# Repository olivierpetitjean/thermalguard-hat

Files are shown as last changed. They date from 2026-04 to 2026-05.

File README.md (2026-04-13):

# ThermalGuard HAT

ThermalGuard HAT is a Raspberry Pi HAT for monitoring and controlling airflow in a server rack or enclosed equipment bay.

This repository contains both the hardware design and the software stack:

- a custom KiCad HAT
- a Python hardware service running on the Raspberry Pi
- a .NET 8 API
- an Angular web dashboard

## Demo

https://github.com/user-attachments/assets/547ba5f1-9dda-4290-b39c-db074ba426f6

## Board Renders And Wiring

### KiCad 3D render - front

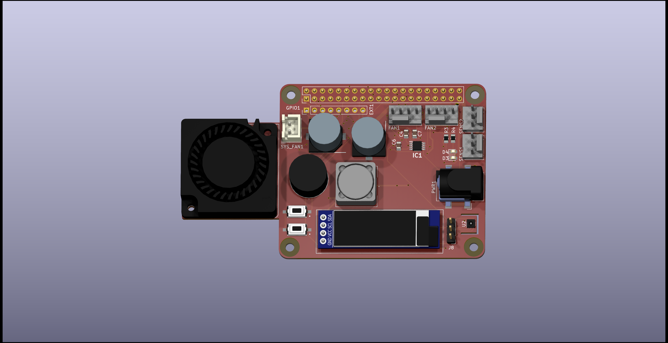
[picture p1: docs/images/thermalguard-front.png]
ThermalGuard HAT front render


### KiCad 3D render - back

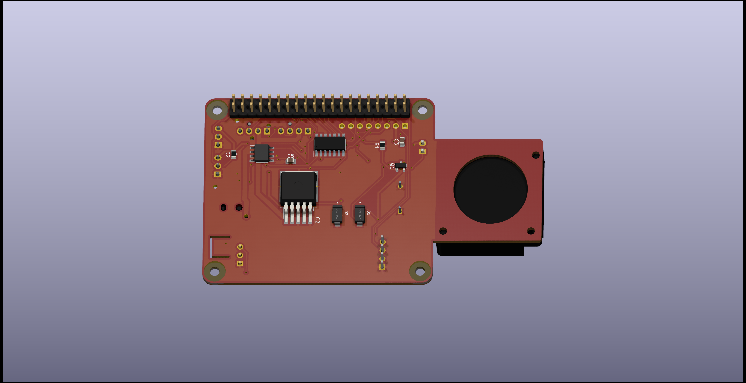
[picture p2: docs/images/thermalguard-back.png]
ThermalGuard HAT back render


### Wiring overview

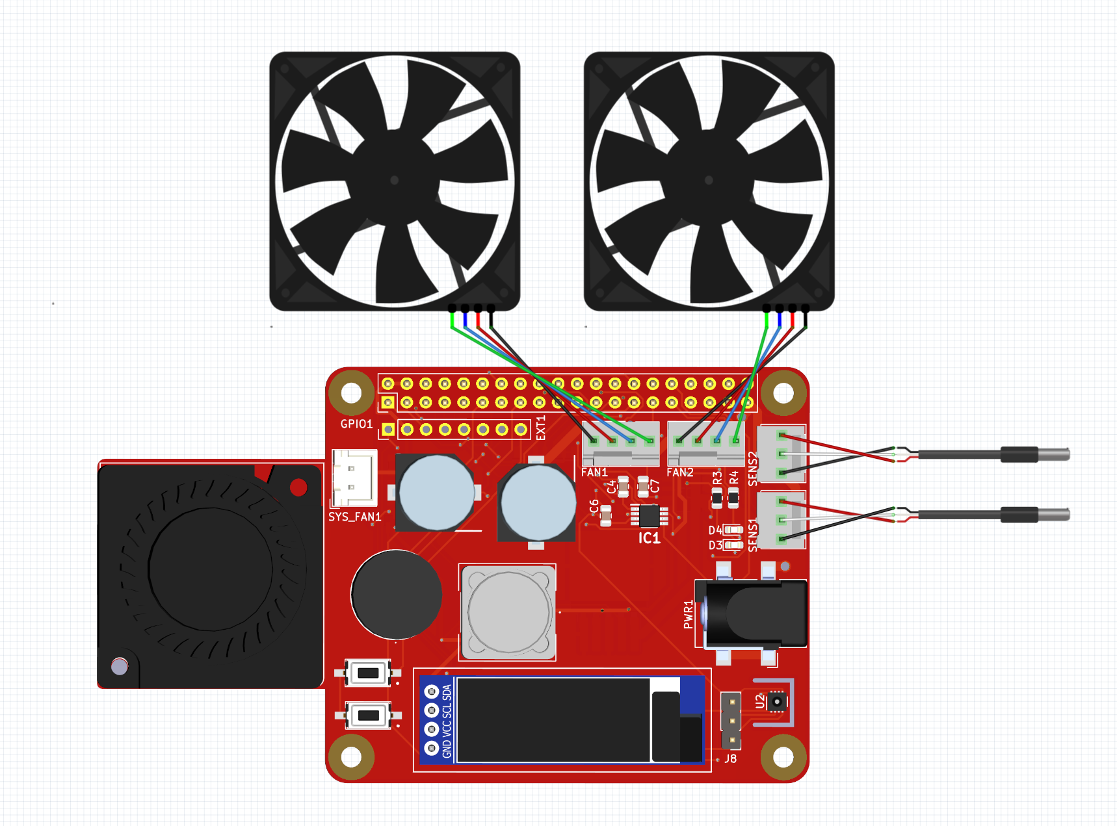
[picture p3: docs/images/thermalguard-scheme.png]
ThermalGuard HAT wiring schematic


## Features

- System monitoring for onboard temperature, power consumption and relative humidity
- Two configurable temperature probes for rack, ambient or custom placement
- Dual fan control with RPM tracking and airflow estimation
- Onboard display showing temperatures, fan RPM, IP address and MAC address
- Automatic fan curves with linked or independent behavior
- Temporary boost mode to force maximum cooling for a defined duration
- Audible alert when a fan or temperature probe is disconnected
- Onboard button control to mute or disable the audible alert
- Web dashboard with live status cards and historical charts
- History browsing by custom period, day or hour
- Local or remote access with authentication
- Kiosk mode for dedicated wall display or rack display usage
- End-to-end installation assistant, including kiosk setup
- Configurable SQLite storage location, including external USB or disk-based storage

The reference platform for this project is a Raspberry Pi 2B. The goal is also to make practical use of older Raspberry Pi hardware for a dedicated monitoring appliance, rather than requiring a newer and more expensive board.

## Repository Structure

```text
thermalguard-hat/
|-- backend/
|   |-- src/      .NET 8 API, persistence, workers, static frontend hosting
|   `-- tests/    .NET test project
|-- frontend/     Angular frontend
|-- services/     Raspberry Pi hardware service and Python tests
|-- kicad/        KiCad project for the HAT PCB
|-- config/       Shared example configuration
|-- docs/         README media assets
`-- install.sh    Raspberry Pi installation script
```

## Hardware

Main hardware blocks currently present in the project:

- Raspberry Pi 2B host
- custom HAT PCB designed in KiCad
- 2 x DS18B20 probes
- 1 x SHT31D temperature and humidity sensor
- 2 x PWM-controlled fans
- fan tachometer and current measurement circuitry
- OLED display and onboard controls

The repository is not only a software project. It also includes the PCB design files required to fabricate the HAT.

## Software Architecture

```mermaid
flowchart TB
    browser([Browser])
    kiosk([Kiosk Display])
    front["Angular Dashboard"]
    api[".NET 8 API"]
    proxy["MQTT Proxy (/mqtt)"]
    mqtt[("Mosquitto Broker")]
    py["Python Hardware Service"]
    db[("SQLite Database")]
    hw["Sensors / Fans / GPIO"]
    svc["systemd"]

    browser -->|"UI"| front
    kiosk -->|"Kiosk UI"| front
    front -->|"REST"| api
    front -->|"WebSocket MQTT"| proxy
    proxy -->|"MQTT"| mqtt
    mqtt -->|"Live telemetry"| proxy
    py -->|"Publish"| mqtt
    py -->|"Store samples"| db
    api -->|"Read / write"| db
    api -->|"Control service"| svc
    svc -->|"Manage"| py
    py -->|"Read / drive"| hw

    classDef client fill:#202534,stroke:#90a4ff,color:#ffffff,stroke-width:1.5px;
    classDef ui fill:#2f3d56,stroke:#6ea8fe,color:#ffffff,stroke-width:1.5px;
    classDef backend fill:#304b46,stroke:#58c4a3,color:#ffffff,stroke-width:1.5px;
    classDef msg fill:#4b3561,stroke:#d08bff,color:#ffffff,stroke-width:1.5px;
    classDef data fill:#5a4330,stroke:#f2a65a,color:#ffffff,stroke-width:1.5px;
    classDef device fill:#4a3f46,stroke:#ff7b7b,color:#ffffff,stroke-width:1.5px;

    class browser,kiosk client;
    class front ui;
    class api,proxy,svc backend;
    class mqtt msg;
    class db data;
    class py,hw device;
```

### Python service

The Python service is the hardware-facing part of the system. It:

- initializes GPIO and sensors
- controls the fans
- reads live measurements
- publishes telemetry on MQTT
- persists data into SQLite

Main entry points:

- [services/main.py](services/main.py)
- [services/service.py](services/service.py)

### Backend API

The backend is a .NET 8 application that:

- serves the web application
- exposes authenticated API endpoints
- stores and queries historical data
- exposes configuration for the frontend
- manages service status operations

Main entry points:

- [backend/src/NetApi/Program.cs](backend/src/NetApi/Program.cs)
- [backend/src/NetApi/Api/Controllers](backend/src/NetApi/Api/Controllers)

### Frontend

The frontend is an Angular application providing:

- dashboard views
- setup and login screens
- kiosk mode
- live MQTT-backed monitoring cards and graphs

Main entry points:

- [frontend/src/app/features/dashboard/pages/dashboard.component.ts](frontend/src/app/features/dashboard/pages/dashboard.component.ts)
- [frontend/src/app/core/app.routes.ts](frontend/src/app/core/app.routes.ts)

## Dashboard

The web interface provides both live monitoring cards and historical charts.

### Live overview

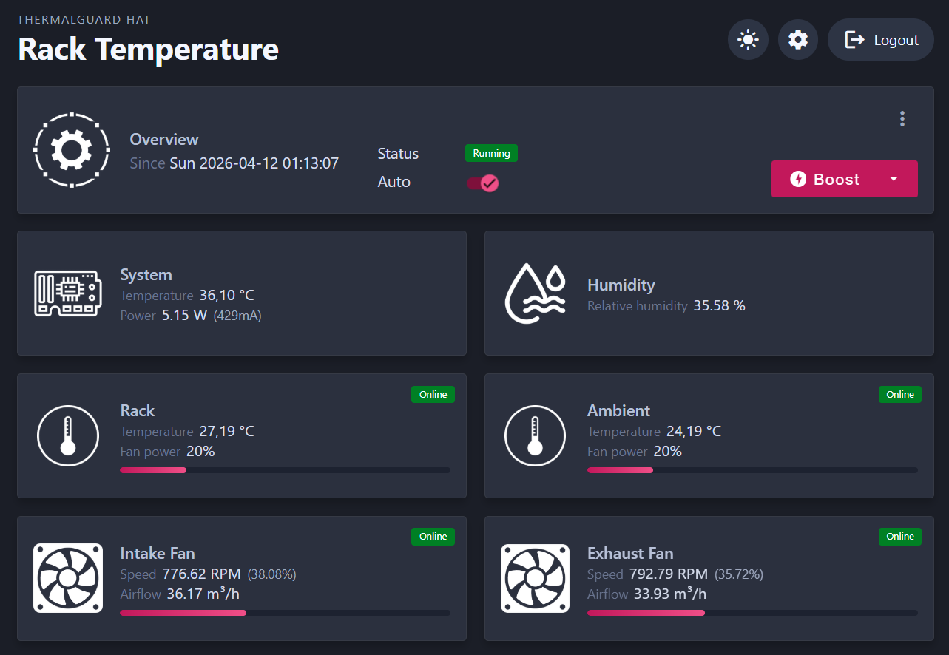
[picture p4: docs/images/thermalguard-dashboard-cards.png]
ThermalGuard HAT dashboard cards


### History view

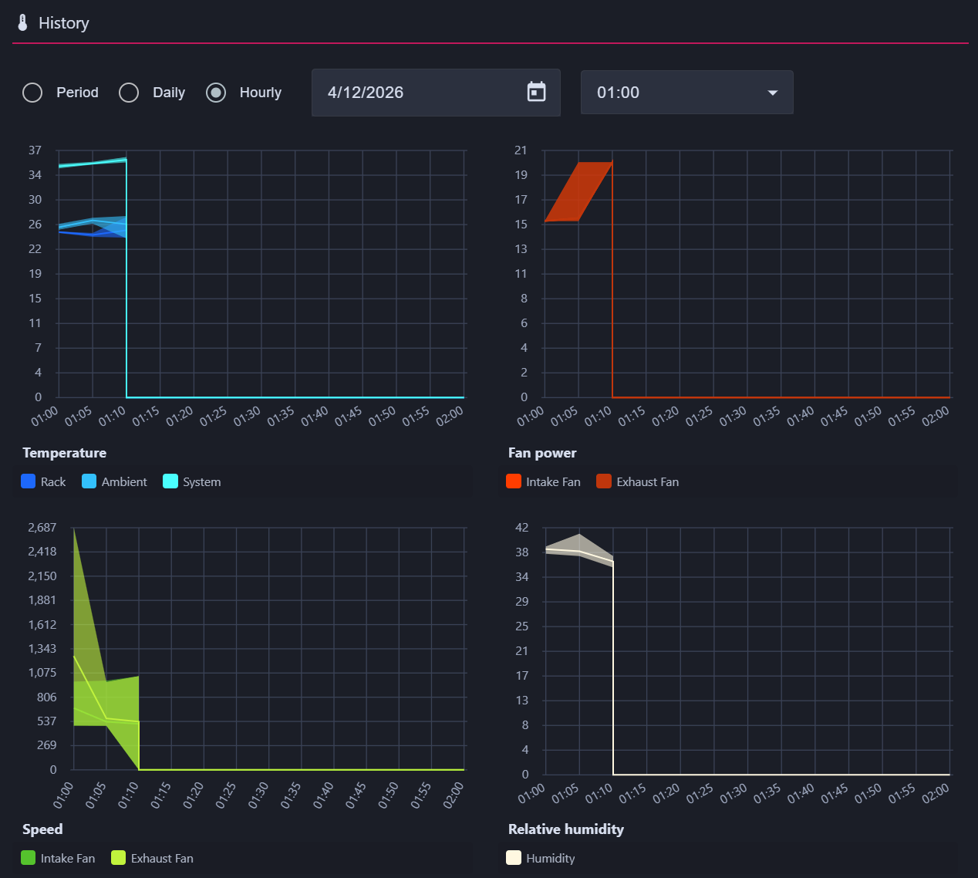
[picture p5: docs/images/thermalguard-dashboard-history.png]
ThermalGuard HAT dashboard history


## Kiosk Mode

ThermalGuard HAT can run in kiosk mode for a dedicated rack display, with optional autologin, Chromium autostart, cursor hiding and screen blanking control.

https://github.com/user-attachments/assets/b98a219e-978e-4593-a772-88bbc4d270f7

## Installation

Run the installation script on the Raspberry Pi as root:

```bash
sudo bash -c "$(curl -sSL https://raw.githubusercontent.com/olivierpetitjean/thermalguard-hat/main/install.sh)"
```

The script installs the software stack, prepares the Raspberry Pi environment and deploys the backend, frontend and Python service.

## Storage Recommendation

For a permanent installation, it is strongly recommended to store the SQLite database on an external storage device such as:

- a USB flash drive
- an external SSD
- an external hard drive

Reason:

- the system performs repeated read and write operations
- keeping the database on the Raspberry Pi SD card increases wear
- the SD card also hosts the operating system, so avoiding unnecessary writes improves reliability

The database location is configurable through the shared connection string in [config/settings.example.json](config/settings.example.json).

## Configuration

The main configuration reference is [config/settings.example.json](config/settings.example.json).

The setup wizard intentionally hides a few advanced low-level values such as the GPIO chip index and PWM channel mapping. They remain available in the shared configuration file if manual tuning is ever needed.

The installation also runs an interactive configuration wizard. Its main sections are:

| Wizard section | What it configures |
|---|---|
| `API & Security` | CORS origin, JWT secret, token lifetime, retention policy and kiosk IP bypass rules |
| `Display & Naming` | Dashboard title, sensor names, fan names, locale, units and airflow display values |
| `Kiosk Mode` | Dedicated kiosk display behavior, local user, inline layout, cursor hiding, autologin, screen blanking and autostart |
| `MQTT Broker` | Local Mosquitto setup, WebSocket port, optional local authentication and optional MQTT bridge settings |
| `1-Wire Temperature Sensors` | Detection and assignment of the two DS18B20 probe identifiers |
| `Thresholds & Timing` | System fan threshold, database write interval, LCD screen standby delay, fan tach filter and PWM timing settings |

If kiosk mode is enabled, the installer then runs a second kiosk-specific step to apply the desktop autologin, screen blanking and Chromium autostart configuration.

### Core settings

| Key | Purpose | Example |
|---|---|---|
| `ConnectionStrings.WebApiDatabase` | Shared SQLite database path used by the API and Python service | `Data Source=/opt/thermalguard-hat/api/db/LocalDatabase.db` |
| `RetentionDays` | Number of days of historical data to keep | `30` |
| `Auth.JwtSecret` | Secret used to sign JWT tokens | `change-me-in-production-at-least-32-chars!!` |
| `Auth.TokenExpiryHours` | JWT validity duration in hours | `12` |
| `AllowedOrigins` | Allowed frontend origin for CORS | `http://raspberrypi.local` |

### MQTT and broker settings

| Key | Purpose | Example |
|---|---|---|
| `BrokerHostSettings.Host` | MQTT broker hostname or IP | `127.0.0.1` |
| `BrokerHostSettings.Port` | MQTT TCP port | `1883` |
| `BrokerHostSettings.WsPort` | MQTT over WebSocket port | `1884` |
| `BrokerHostSettings.User` | MQTT username | `your-user` |
| `BrokerHostSettings.Password` | MQTT password | `your-password` |
| `BrokerHostSettings.UseTls` | Enable TLS for broker communication | `false` |
| `Mosquitto.Local.Authentication.Enabled` | Enable authentication on local Mosquitto | `false` |
| `Mosquitto.Bridge.Enabled` | Enable broker bridge mode | `false` |
| `Mosquitto.Bridge.Host` | Upstream broker hostname | `mqtt.example.com` |
| `Mosquitto.Bridge.Port` | Upstream broker port | `1883` |

### Sensors, cooling and hardware pins

| Key | Purpose | Example |
|---|---|---|
| `Python.Sensor1Uid` | 1-Wire identifier for probe 1 | `xxxxxxxxxxxx` |
| `Python.Sensor2Uid` | 1-Wire identifier for probe 2 | `xxxxxxxxxxxx` |
| `Python.SysFanThreshold` | Temperature threshold for the system fan | `38` |
| `Python.Fan1Pin` | PWM pin for fan 1 | `12` |
| `Python.Fan2Pin` | PWM pin for fan 2 | `13` |
| `Python.Fan1Sensor` | Tachometer input for fan 1 | `25` |
| `Python.Fan2Sensor` | Tachometer input for fan 2 | `24` |
| `Python.SystemFan` | GPIO pin for the auxiliary system fan | `23` |
| `Python.SysBuzzer` | GPIO pin for the buzzer | `22` |
| `Python.Button1Pin` | GPIO pin for button 1 | `17` |
| `Python.Button2Pin` | GPIO pin for button 2 | `0` |

### Display and UI labels

| Key | Purpose | Example |
|---|---|---|
| `Display.DashboardTitle` | Dashboard title shown in the UI | `Dashboard` |
| `Display.Sensor1Name` | Label for probe 1 | `Rack` |
| `Display.Sensor2Name` | Label for probe 2 | `Ambient` |
| `Display.Fan1Name` | Label for fan 1 | `Intake Fan` |
| `Display.Fan2Name` | Label for fan 2 | `Exhaust Fan` |
| `Display.Locale` | UI locale | `en-US` |
| `Display.TemperatureUnit` | Temperature unit | `C` |
| `Display.AirflowUnit` | Airflow unit displayed in the UI | `m3h` |
| `Display.Fan1MaxAirflow` | Reference airflow value for fan 1 | `95.0` |
| `Display.Fan2MaxAirflow` | Reference airflow value for fan 2 | `95.0` |

### Kiosk settings

| Key | Purpose | Example |
|---|---|---|
| `Kiosk.BypassIPs` | IP addresses allowed to access kiosk mode without standard login | `[]` |
| `KioskSetup.Enabled` | Enable kiosk setup during installation | `false` |
| `KioskSetup.User` | Desktop user used for kiosk autologin | `pi` |
| `KioskSetup.HideCursor` | Hide mouse cursor in kiosk mode | `true` |
| `KioskSetup.DesktopAutologin` | Enable desktop autologin | `true` |
| `KioskSetup.DisableScreenBlanking` | Disable screen blanking and sleep | `true` |
| `KioskSetup.Autostart` | Launch kiosk automatically on boot | `true` |

## Security

- API endpoints are protected with JWT authentication except the authentication bootstrap endpoints
- passwords are hashed with BCrypt
- the JWT secret must be changed before deployment
- CORS origins should be restricted to the actual deployed frontend origin

## License

MIT. See [LICENSE](LICENSE).

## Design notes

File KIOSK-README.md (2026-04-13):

# Kiosk Setup Notes

This document records the validated steps required to configure ThermalGuard HAT in kiosk mode on Raspberry Pi OS.

## Goal

Boot directly into Chromium kiosk mode on:

```text
http://localhost/kiosk?mode=inline
```

The final kiosk setup should have:

- no kiosk page title or subtitle
- desktop autologin enabled
- screen blanking disabled
- direct access to `/kiosk` working correctly

## Prerequisites

- Raspberry Pi OS with a graphical desktop
- ThermalGuard HAT already installed on the Pi
- the API reachable locally on the Pi
- the backend SPA fallback deployed so `/kiosk` works on direct access

## 1. First Boot

On a fresh Raspberry Pi OS installation, if no user account was preconfigured, the first-boot wizard will ask you to create:

- a username
- a password

This step must be completed before using `raspi-config` or enabling desktop autologin.

## 2. Check That the Display Is Detected

To confirm which HDMI output is being used:

```bash
ls -1 /sys/class/drm/card?-HDMI-A-?/status
cat /sys/class/drm/card?-HDMI-A-?/status
```

Validated result in this setup:

```text
HDMI-A-1
connected
```

To inspect the active video mode in more detail:

```bash
kmsprint | sed -n '/HDMI-A-1/,+25p'
```

`kms++` is only used as a display diagnostics tool. It helps verify:

- which connector is actually in use
- the active resolution
- the available display modes

## 3. Enable Desktop Autologin

```bash
sudo raspi-config
```

Then go to:

- `System Options`
- `Boot / Auto Login`
- `Desktop Autologin`

## 4. Disable Screen Blanking

```bash
sudo raspi-config
```

Then go to:

- `Display Options`
- `Screen Blanking`
- `No`

## 5. Launch Chromium Automatically at Startup

On Raspberry Pi OS Bookworm with `labwc`, desktop autostart commands live in:

```text
~/.config/labwc/autostart
```

Create the directory if needed:

```bash
mkdir -p ~/.config/labwc
```

Validated autostart content:

```bash
chromium "http://localhost/kiosk?mode=inline" --kiosk --noerrdialogs --disable-infobars --no-first-run --start-maximized --password-store=basic --user-data-dir=/home/olivier/.config/chromium-kiosk &
```

Command to write it directly:

```bash
printf '%s\n' 'chromium "http://localhost/kiosk?mode=inline" --kiosk --noerrdialogs --disable-infobars --no-first-run --start-maximized --password-store=basic --user-data-dir=/home/olivier/.config/chromium-kiosk &' > ~/.config/labwc/autostart
```

Verification:

```bash
cat ~/.config/labwc/autostart
```

## 6. Manual Test Before Enabling Autostart

Before relying on autostart, it is useful to test Chromium manually from the graphical session.

Validated command:

```bash
DISPLAY=:0 XDG_RUNTIME_DIR=/run/user/1000 chromium "http://localhost/kiosk?mode=inline" --kiosk --noerrdialogs --disable-infobars --no-first-run --start-maximized --password-store=basic --user-data-dir=/home/olivier/.config/chromium-kiosk
```

Notes:

- `--password-store=basic` avoids the system keyring popup
- `--user-data-dir=/home/olivier/.config/chromium-kiosk` isolates a dedicated Chromium profile for kiosk mode
- Chromium may still print warnings in the terminal without affecting kiosk mode

## 7. Validation Reboot

```bash
sudo reboot
```

After reboot, verify:

- desktop autologin is active
- Chromium starts automatically
- the kiosk URL loads correctly
- no Chromium popup appears
- screen blanking stays disabled

## 8. Useful Kiosk URL Parameter

The compact horizontal kiosk layout is enabled with:

```text
mode=inline
```

Example:

```text
/kiosk?mode=inline
```

Without this parameter, the kiosk uses its default layout.

## 9. Useful Notes

- The display rotation tests done with `wlr-randr` were rolled back and are not part of the final target setup.
- The attempts to rotate the display via `/boot/firmware/cmdline.txt` were also rolled back and are not part of the final validated procedure.
- If `/kiosk` does not work on direct access, verify that the deployed backend includes the ASP.NET SPA fallback.

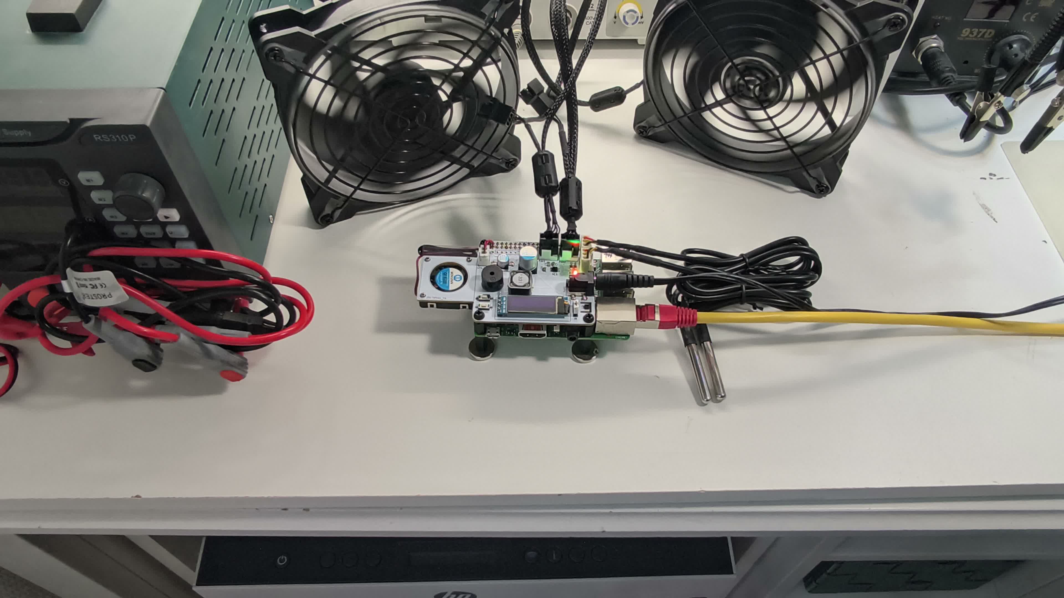
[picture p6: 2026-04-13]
docs/images/thermalguard-demo-poster.jpg

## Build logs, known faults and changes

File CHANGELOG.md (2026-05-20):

# Changelog

All notable changes to this project will be documented in this file.

## [1.1.0] - 2026-05-20

### Added

- Added multi-mode fan condition control with `linked_fans`, `independent`, and `differential` modes.
- Added frontend controls for selecting the control mode and related trigger options in the settings UI.
- Added a `DisableFanAlerts` option to suppress fan disconnect alerts for low-speed fans that intentionally stop at low PWM values.
- Added the fan alert option to the web setup flow and the post-install configuration wizard.
- Added installation-time synchronization of runtime alert preferences before the Python sensor service starts.

### Changed

- Updated the Python hardware service to apply the new control modes when computing fan power.
- Updated the backend settings model and SQLite schema to persist the new control settings and `DisableFanAlerts`.
- Improved the installation/configuration flow so setup choices are applied consistently to the runtime database.

### Fixed

- Prevented false fan disconnect alerts on fans that report `0 RPM` when running below their startup threshold.

### Docs

- Updated demo video links in the README.

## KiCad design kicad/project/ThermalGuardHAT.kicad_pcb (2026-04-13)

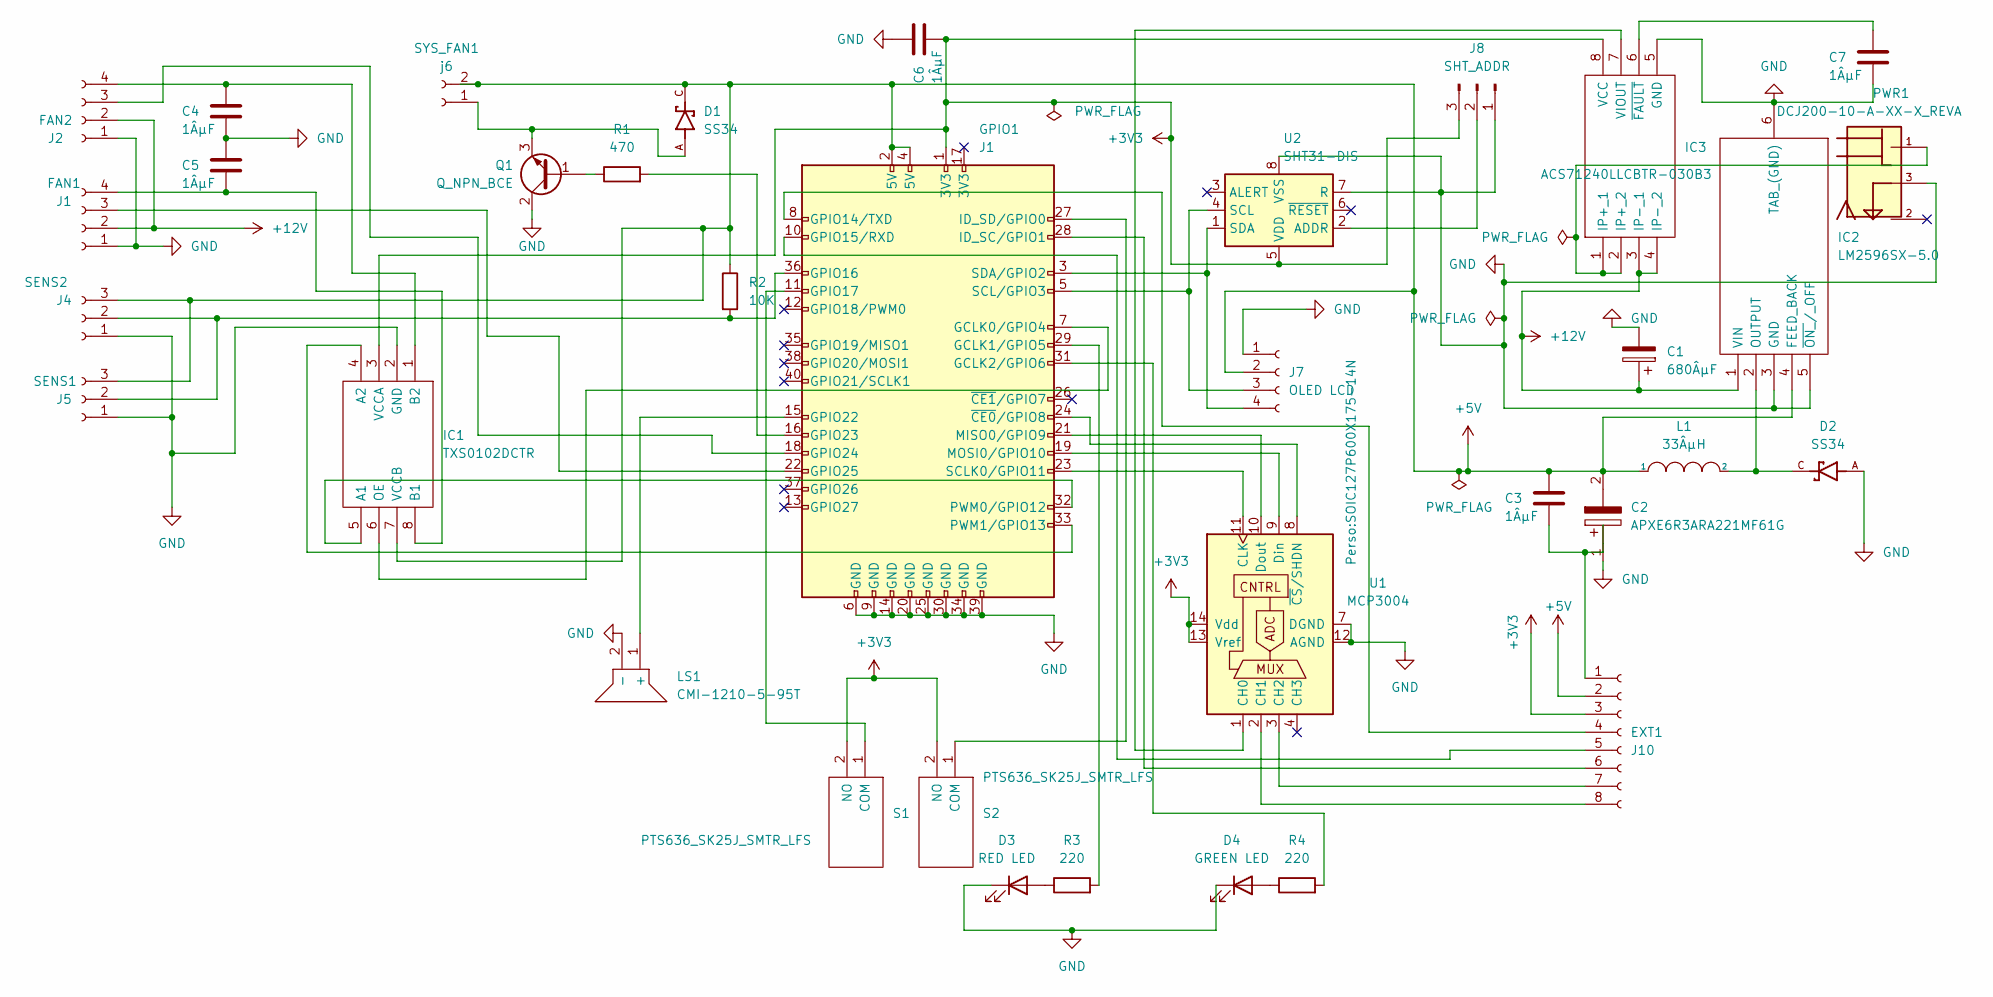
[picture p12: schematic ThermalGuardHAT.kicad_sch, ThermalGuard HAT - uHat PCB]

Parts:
C1: 680ÂµF; CAPAE1030X1270N
C2: APXE6R3ARA221MF61G; CAPAE1030X1270N; Mouser Part Number 661-APXE6R3A221MF61G
C3, C4, C5, C6, C7: 1ÂµF; C_0805_2012Metric
D1, D2: SS34; DIOM4325X250N; PARTREV 31 Aug 2016
D3: RED LED; LED_0603_1608Metric
D4: GREEN LED; LED_0603_1608Metric
EXT1: J10; PinHeader_1x08_P2.54mm_Vertical
FAN1: J1; FanPinHeader_1x04_P2.54mm_Vertical
FAN2: J2; FanPinHeader_1x04_P2.54mm_Vertical
GPIO1: J1; PinHeader_2x20_P2.54mm_Vertical
IC1: TXS0102DCTR; SOP65P400X130-8N; Mouser Part Number 595-TXS0102DCTR
IC2: LM2596SX-5.0; TO-263-5_TabPin6; Mouser Part Number 926-LM2596SX-5.0NOPB
IC3: ACS71240LLCBTR-030B3; SOIC127P600X175-8N; Mouser Part Number 250-71240LLCBTR030B3
J7: OLED LCD; PinHeader_1x04_P2.54mm_Vertical
J8: SHT_ADDR; PinHeader_1x03_P2.54mm_Vertical
L1: 33ÂµH; SRR1280-331K
LS1: CMI-1210-5-95T; CMI1210595T; Mouser Part Number 179-CMI-1210-5-95T
PWR1: DCJ200-10-A-XX-X_REVA; BarrelJack_CLIFF_FC681465S_SMT_Horizontal
Q1: Q_NPN_BCE; SOT-23
R1: 470; R_0805_2012Metric
R2: 10K; R_0805_2012Metric
R3, R4: 220; R_0805_2012Metric
S1, S2: PTS636_SK25J_SMTR_LFS; PTS636SK25JSMTRLFS; Mouser Part Number 611-PTS636SK25JSMTRL
SENS1: J5; FanPinHeader_1x03_P2.54mm_Vertical
SENS2: J4; FanPinHeader_1x03_P2.54mm_Vertical
SYS_FAN1: j6; JST_XH_B2B-XH-A_1x02_P2.50mm_Vertical
U1: MCP3004; SOIC127P600X175-14N
U2: SHT31-DIS; Sensirion_DFN-8-1EP_2.5x2.5mm_P0.5mm_EP1.1x1.7mm

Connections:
+3V3: C6.2, EXT1.3, GPIO1.1 (3V3), IC1.3 (VCCA), IC3.8 (VCC), J8.3, S1.2 (NO), S2.2 (NO), U1.13 (Vref), U1.14 (Vdd), U2.5 (VDD)
+5V: C2.2, C3.1, D1.C, EXT1.2, GPIO1.2 (5V), GPIO1.4 (5V), IC1.7 (VCCB), IC2.4 (FEED_BACK), J7.2, L1.1, R2.1, SENS1.3, SENS2.3, SYS_FAN1.2
+12V: C1.1, FAN1.2, FAN2.2, IC2.1 (VIN), IC3.3 (IP-_1), IC3.4 (IP-_2)
GND: C1.2, C2.1, C4.2, C5.1, C6.1, C7.2, D2.A, D3.1 (K), D4.1 (K), FAN1.1, FAN2.1, GPIO1.6 (GND), GPIO1.9 (GND), GPIO1.14 (GND), GPIO1.20 (GND), GPIO1.25 (GND), GPIO1.30 (GND), GPIO1.34 (GND), GPIO1.39 (GND), IC1.2 (GND), IC2.3 (GND), IC2.5 (~ON_/_OFF), IC2.6 (TAB_(GND)), IC3.5 (GND), J7.1, J8.1, LS1.2 (-), PWR1.3, Q1.2 (C), SENS1.1, SENS2.1, U1.7 (DGND), U1.12 (AGND), U2.7 (R), U2.8 (VSS), U2.9 (VSS)
unnamed: C3.2, EXT1.1
unnamed: C4.1, FAN2.4, IC1.1 (B2)
unnamed: C5.2, FAN1.4, IC1.8 (B1)
unnamed: C7.1, IC3.6 (~FAULT)
unnamed: D1.A, Q1.3 (E), SYS_FAN1.1
unnamed: D2.C, IC2.2 (OUTPUT), L1.2
unnamed: D3.2 (A), R3.1
unnamed: D4.2 (A), R4.1
unnamed: EXT1.4, GPIO1.8 (GPIO14/TXD)
unnamed: EXT1.5, GPIO1.10 (GPIO15/RXD)
unnamed: EXT1.6, GPIO1.28 (ID_SC/GPIO1)
unnamed: EXT1.7, U1.3 (CH2)
unnamed: EXT1.8, U1.2 (CH1)
unnamed: FAN1.3, GPIO1.22 (GPIO25)
unnamed: FAN2.3, GPIO1.18 (GPIO24)
unnamed: GPIO1.3 (SDA/GPIO2), J7.4, U2.1 (SDA)
unnamed: GPIO1.5 (SCL/GPIO3), J7.3, U2.4 (SCL)
unnamed: GPIO1.7 (GCLK0/GPIO4), IC1.6 (OE)
unnamed: GPIO1.11 (GPIO17), S1.1 (COM)
unnamed: GPIO1.15 (GPIO22), LS1.1 (+)
unnamed: GPIO1.16 (GPIO23), R1.2
unnamed: GPIO1.19 (MOSI0/GPIO10), U1.9 (Din)
unnamed: GPIO1.21 (MISO0/GPIO9), U1.10 (Dout)
unnamed: GPIO1.23 (SCLK0/GPIO11), U1.11 (CLK)
unnamed: GPIO1.24 (~CE0/GPIO8), U1.8 (~CS/SHDN)
unnamed: GPIO1.27 (ID_SD/GPIO0), S2.1 (COM)
unnamed: GPIO1.29 (GCLK1/GPIO5), R3.2
unnamed: GPIO1.31 (GCLK2/GPIO6), R4.2
unnamed: GPIO1.32 (PWM0/GPIO12), IC1.5 (A1)
unnamed: GPIO1.33 (PWM1/GPIO13), IC1.4 (A2)
unnamed: GPIO1.36 (GPIO16), R2.2, SENS1.2, SENS2.2
unnamed: IC3.1 (IP+_1), IC3.2 (IP+_2), PWR1.1
unnamed: IC3.7 (VIOUT), U1.1 (CH0)
unnamed: J8.2, U2.2 (ADDR)
unnamed: Q1.1 (B), R1.1

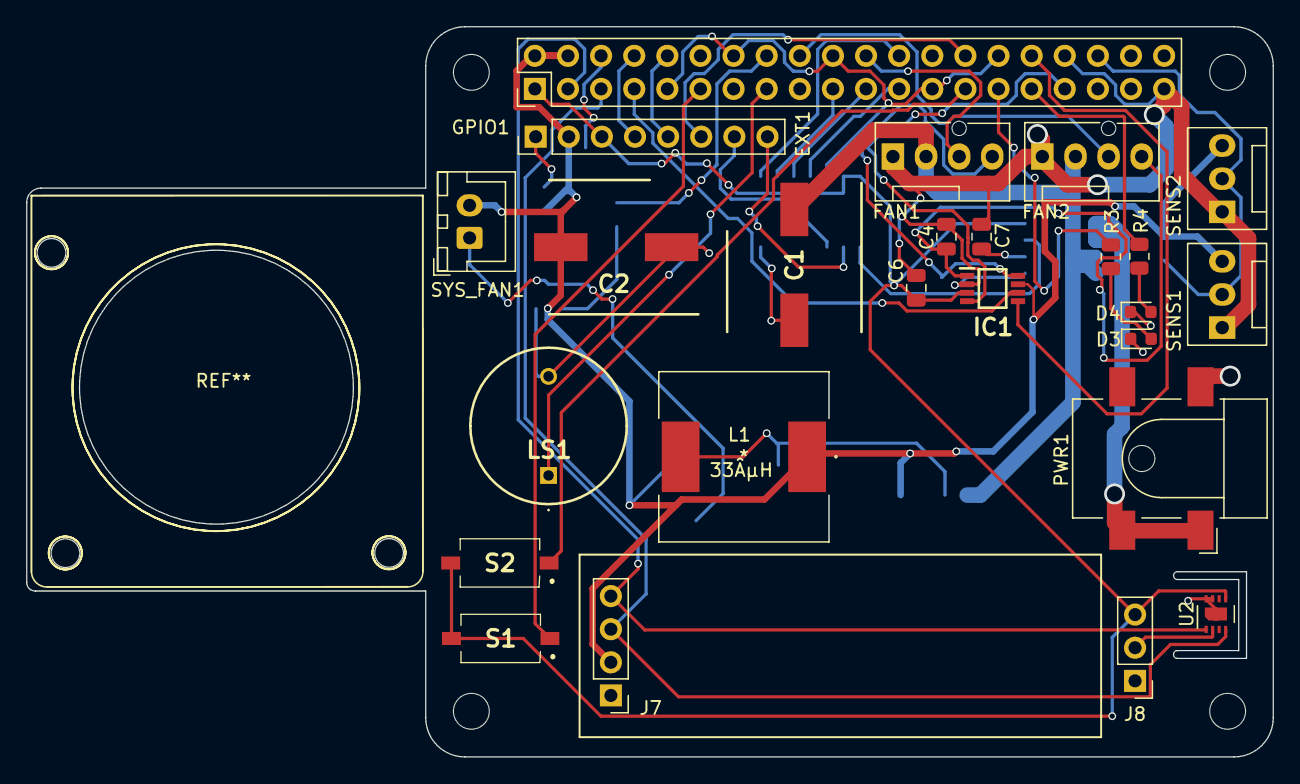
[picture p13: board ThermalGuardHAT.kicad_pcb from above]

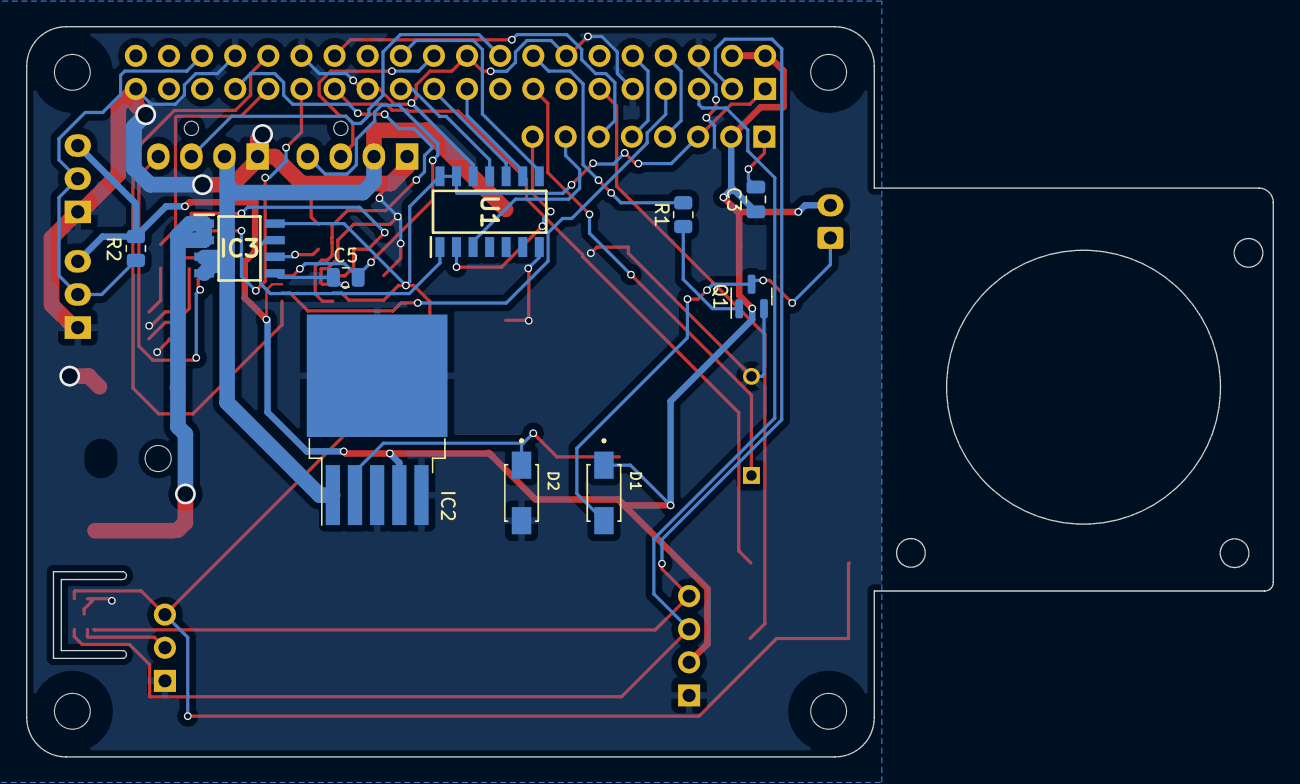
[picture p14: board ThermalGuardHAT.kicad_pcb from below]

Board: 2 copper layers, 95.6 x 56.0 mm, 35 parts (10 on the bottom side), 39 nets.

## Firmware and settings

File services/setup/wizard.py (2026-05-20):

#!/usr/bin/env python3
"""
ThermalGuard HAT - Configuration wizard
Uses the shared config/settings.json file, reads minimal API defaults from
appsettings.json when needed for migration/bootstrap, and generates the
Mosquitto configuration.
"""

import argparse
import glob
import ipaddress
import json
import os
import secrets
import sqlite3
import string
import subprocess
import sys
import socket
from datetime import datetime

# ---------------------------------------------------------------------------
# Helpers
# ---------------------------------------------------------------------------

RED    = '\033[0;31m'
GREEN  = '\033[0;32m'
YELLOW = '\033[1;33m'
CYAN   = '\033[0;36m'
BOLD   = '\033[1m'
NC     = '\033[0m'

def section(title):
    print(f"\n{CYAN}{'=' * 50}{NC}")
    print(f"{CYAN}  {title}{NC}")
    print(f"{CYAN}{'=' * 50}{NC}")

def ok(msg):    print(f"{GREEN}[OK]{NC} {msg}")
def warn(msg):  print(f"{YELLOW}[!]{NC} {msg}")
def error(msg): print(f"{RED}[x]{NC} {msg}"); sys.exit(1)

def ask(prompt, default=None, secret=False):
    if default is not None:
        display = f"{prompt} [{default}]: "
    else:
        display = f"{prompt}: "
    while True:
        if secret:
            import getpass
            value = getpass.getpass(display)
        else:
            value = input(display).strip()
        if value:
            return value
        if default is not None:
            return default
        print("  This field is required.")

def ask_int(prompt, default=None, min_val=None, max_val=None):
    while True:
        raw = ask(prompt, default=str(default) if default is not None else None)
        try:
            val = int(raw)
            if min_val is not None and val < min_val:
                print(f"  Must be >= {min_val}.")
                continue
            if max_val is not None and val > max_val:
                print(f"  Must be <= {max_val}.")
                continue
            return val
        except ValueError:
            print("  Please enter a valid integer.")

def ask_float(prompt, default=None, min_val=None, max_val=None):
    while True:
        raw = ask(prompt, default=str(default) if default is not None else None)
        try:
            val = float(raw.replace(",", "."))
            if min_val is not None and val < min_val:
                print(f"  Must be >= {min_val}.")
                continue
            if max_val is not None and val > max_val:
                print(f"  Must be <= {max_val}.")
                continue
            return val
        except ValueError:
            print("  Please enter a valid number.")

def ask_bool(prompt, default=True):
    default_str = "Y/n" if default else "y/N"
    raw = input(f"{prompt} [{default_str}]: ").strip().lower()
    if not raw:
        return default
    return raw in ('y', 'yes')

def ask_choice(prompt, choices, default=None, case_sensitive=False):
    normalized_choices = choices if case_sensitive else [choice.lower() for choice in choices]
    while True:
        value = ask(prompt, default=default)
        candidate = value if case_sensitive else value.lower()
        if candidate in normalized_choices:
            if case_sensitive:
                return value
            return choices[normalized_choices.index(candidate)]
        print(f"  Please enter one of: {', '.join(choices)}.")

def ask_ip_list(prompt, default=None):
    while True:
        raw = ask(prompt, default=default)
        if not raw.strip():
            return []

        values = [value.strip() for value in raw.split(",") if value.strip()]
        try:
            normalized = [str(ipaddress.ip_address(value)) for value in values]
            return normalized
        except ValueError as ex:
            print(f"  Invalid IP address: {ex}.")

def generate_secret(length=48):
    alphabet = string.ascii_letters + string.digits
    return ''.join(secrets.choice(alphabet) for _ in range(length))

def masked_secret(value):
    return "********" if value else None


def connection_string_to_db_path(connection_string, default_path):
    if not connection_string:
        return default_path

    for segment in connection_string.split(";"):
        segment = segment.strip()
        if not segment:
            continue
        if "=" not in segment:
            continue
        key, value = segment.split("=", 1)
        if key.strip().lower() == "data source":
            return value.strip()

    return default_path


def db_path_to_connection_string(db_path):
    return f"Data Source={db_path}"

# ---------------------------------------------------------------------------
# 1-Wire sensor scan
# ---------------------------------------------------------------------------

W1_BASE = "/sys/bus/w1/devices"

def scan_w1_sensors():
    pattern = os.path.join(W1_BASE, "28-*")
    return [os.path.basename(p) for p in glob.glob(pattern)]

def normalize_w1_uid(uid):
    return uid[3:] if uid.startswith("28-") else uid

def read_w1_temp(uid):
    path = os.path.join(W1_BASE, uid, "temperature")
    try:
        with open(path) as f:
            return int(f.read().strip()) / 1000.0
    except Exception:
        return None

def configure_sensors(settings):
    section("1-Wire Temperature Sensors")

    sensors = scan_w1_sensors()
    if not sensors:
        warn("No 1-Wire sensors detected. Check wiring and /boot/config.txt (dtoverlay=w1-gpio).")
        warn("You can set sensor UIDs manually later in the shared settings file.")
        settings['sensor1Uid'] = ask("Sensor 1 UID", default=settings.get('sensor1Uid', "xxxxxxxxxxxx"))
        settings['sensor2Uid'] = ask("Sensor 2 UID", default=settings.get('sensor2Uid', "xxxxxxxxxxxx"))
        return

    print(f"\n  Detected {len(sensors)} sensor(s):\n")
    for i, uid in enumerate(sensors):
        temp = read_w1_temp(uid)
        temp_str = f"{temp:.1f} C" if temp is not None else "unreadable"
        print(f"  [{i+1}] {uid}  ->  {temp_str}")

    print()

    normalized_sensors = [normalize_w1_uid(uid) for uid in sensors]
    default_sensor1_index = normalized_sensors.index(settings.get('sensor1Uid')) + 1 if settings.get('sensor1Uid') in normalized_sensors else 1
    default_sensor2_index = normalized_sensors.index(settings.get('sensor2Uid')) + 1 if settings.get('sensor2Uid') in normalized_sensors else 2

    if len(sensors) >= 1:
        idx = ask_int("Assign sensor 1 - enter number", default=default_sensor1_index, min_val=1, max_val=len(sensors))
        settings['sensor1Uid'] = normalize_w1_uid(sensors[idx - 1])
        ok(f"Sensor 1: {settings['sensor1Uid']}")

    if len(sensors) >= 2:
        while True:
            proposed_idx2 = default_sensor2_index if default_sensor2_index != idx else (2 if idx != 2 and len(sensors) >= 2 else 1)
            idx2 = ask_int("Assign sensor 2 - enter number", default=proposed_idx2, min_val=1, max_val=len(sensors))
            if idx2 == idx:
                print("  Sensor 2 must be different from sensor 1.")
                continue
            settings['sensor2Uid'] = normalize_w1_uid(sensors[idx2 - 1])
            ok(f"Sensor 2: {settings['sensor2Uid']}")
            break
    else:
        warn("Only one sensor detected. Sensor 2 will be unset.")
        settings['sensor2Uid'] = "xxxxxxxxxxxx"

# ---------------------------------------------------------------------------
# Timing / thresholds
# ---------------------------------------------------------------------------

def configure_thresholds(settings):
    section("Thresholds & Timing")

    settings['sysFanThreshold'] = ask_int(
        "System fan activation threshold (C)", default=settings.get('sysFanThreshold', 38), min_val=20, max_val=80)
    settings['saveDelaySecond'] = ask_int(
        "Database save interval (seconds)", default=settings.get('saveDelaySecond', 15), min_val=5, max_val=300)
    settings['screenStandByDelay'] = ask_int(
        "LCD screen standby delay (seconds)", default=settings.get('screenStandByDelay', 30), min_val=10, max_val=600)
    settings['fanFrequency'] = ask_int(
        "Fan PWM frequency (Hz)", default=settings.get('fanFrequency', 25000), min_val=1000, max_val=100000)
    settings['fanPWMResolution'] = ask_int(
        "Fan PWM resolution", default=settings.get('fanPWMResolution', 1000), min_val=100, max_val=10000)
    settings['fanTachGlitchFilterUs'] = ask_int(
        "Fan tach glitch filter (microseconds)",
        default=settings.get('fanTachGlitchFilterUs', 50),
        min_val=0,
        max_val=5000)
    settings['fanTempoSeconds'] = ask_int(
        "Fan ramp-up delay (seconds)", default=settings.get('fanTempoSeconds', 30), min_val=0, max_val=120)

# ---------------------------------------------------------------------------
# MQTT
# ---------------------------------------------------------------------------

MOSQUITTO_CONF_PATH = "/etc/mosquitto/conf.d/thermalguard-hat.conf"

def configure_mqtt(settings, api_settings):
    section("MQTT Broker")

    current_local_port = int(settings.get('mqttPort', api_settings.get('BrokerHostSettings', {}).get('Port', 1883)))
    current_local_ws_port = int(api_settings.get('BrokerHostSettings', {}).get('WsPort', 1884))
    current_local_user = settings.get('mqttUser', '')
    current_local_password = settings.get('mqttPassword', '')

    bridge_enabled = bool(settings.get('mqttBridgeEnabled', False))
    current_bridge_host = settings.get('mqttBridgeHost', '')
    current_bridge_port = int(settings.get('mqttBridgePort', 1883))
    current_bridge_use_tls = bool(settings.get('mqttBridgeUseTls', False))
    current_bridge_user = settings.get('mqttBridgeUser', '')
    current_bridge_password = settings.get('mqttBridgePassword', '')

    use_local_broker = ask_bool("Use local Mosquitto broker?", default=not bridge_enabled)
    use_bridge = not use_local_broker

    local_tcp_port = ask_int("Local MQTT TCP port", default=current_local_port, min_val=1, max_val=65535)
    local_ws_port = ask_int("Local MQTT WebSocket port (used by the API proxy)", default=current_local_ws_port, min_val=1, max_val=65535)

    if use_bridge:
        bridge_host = ask("Remote broker host", default=current_bridge_host or "broker.example.com")
        bridge_port = ask_int("Remote broker port", default=current_bridge_port, min_val=1, max_val=65535)
        bridge_use_tls = ask_bool("Use TLS for the bridge connection?", default=current_bridge_use_tls)
        bridge_user = ask("Remote MQTT username", default=current_bridge_user)
        if bridge_user:
            bridge_password_input = ask("Remote MQTT password", default=masked_secret(current_bridge_password), secret=True)
            bridge_password = current_bridge_password if bridge_password_input == "********" else bridge_password_input
        else:
            bridge_password = ""

        _configure_mosquitto_bridge(
            local_tcp_port,
            local_ws_port,
            bridge_host,
            bridge_port,
            bridge_use_tls,
            bridge_user,
            bridge_password,
        )
        ok(f"Mosquitto configured locally (TCP:{local_tcp_port}, WS:{local_ws_port}) with bridge to {bridge_host}:{bridge_port}")
    else:
        use_local_auth = ask_bool("Enable local MQTT authentication?", default=bool(current_local_user))
        local_user = ""
        local_password = ""
        if use_local_auth:
            local_user = ask("Local MQTT username", default=current_local_user)
            local_password_input = ask("Local MQTT password", default=masked_secret(current_local_password), secret=True)
            local_password = current_local_password if local_password_input == "********" else local_password_input
            _configure_mosquitto_local(local_tcp_port, local_ws_port, local_user, local_password)
        else:
            _configure_mosquitto_local(local_tcp_port, local_ws_port, None, None)
        bridge_host = ""
        bridge_port = 1883
        bridge_use_tls = False
        bridge_user = ""
        bridge_password = ""
        local_user = local_user if use_local_auth else ""
        local_password = local_password if use_local_auth else ""
        ok(f"Mosquitto configured locally (TCP:{local_tcp_port}, WS:{local_ws_port})")

    settings['mqttHost'] = "127.0.0.1"
    settings['mqttPort'] = local_tcp_port
    settings['mqttUseTls'] = False
    settings['mqttUser'] = local_user if not use_bridge else ""
    settings['mqttPassword'] = local_password if not use_bridge else ""
    settings['mqttBridgeEnabled'] = use_bridge
    settings['mqttBridgeHost'] = bridge_host
    settings['mqttBridgePort'] = bridge_port
    settings['mqttBridgeUseTls'] = bridge_use_tls
    settings['mqttBridgeUser'] = bridge_user
    settings['mqttBridgePassword'] = bridge_password

    api_settings['BrokerHostSettings']['Host'] = "127.0.0.1"
    api_settings['BrokerHostSettings']['Port'] = local_tcp_port
    api_settings['BrokerHostSettings']['WsPort'] = local_ws_port
    api_settings['BrokerHostSettings']['UseTls'] = False
    api_settings['BrokerHostSettings']['User'] = local_user if not use_bridge else ""
    api_settings['BrokerHostSettings']['Password'] = local_password if not use_bridge else ""


def _configure_mosquitto_local(tcp_port, ws_port, user, password):
    lines = [
        f"listener {tcp_port} 127.0.0.1",
        f"listener {ws_port} 127.0.0.1",
        "protocol websockets",
    ]
    if user and password:
        passwd_file = "/etc/mosquitto/thermalguard-hat.passwd"
        lines += [
            f"password_file {passwd_file}",
            "allow_anonymous false",
        ]
        try:
            subprocess.run(
                ["mosquitto_passwd", "-b", "-c", passwd_file, user, password],
                check=True, capture_output=True
            )
        except Exception as e:
            warn(f"Could not create Mosquitto password file: {e}")
    else:
        lines.append("allow_anonymous true")

    os.makedirs(os.path.dirname(MOSQUITTO_CONF_PATH), exist_ok=True)
    with open(MOSQUITTO_CONF_PATH, "w") as f:
        f.write("\n".join(lines) + "\n")


def _configure_mosquitto_bridge(local_tcp_port, local_ws_port, remote_host, remote_port, remote_use_tls, remote_user, remote_password):
    lines = [
        f"listener {local_tcp_port} 127.0.0.1",
        f"listener {local_ws_port} 127.0.0.1",
        "protocol websockets",
        "allow_anonymous true",
        "",
        "connection thermalguard-hat-bridge",
        f"address {remote_host}:{remote_port}",
        "start_type automatic",
        "notifications_local_only true",
        "try_private true",
        "topic temperatures both 0",
        "topic rpm both 0",
        "topic power both 0",
        "topic system both 0",
        "topic maxrefs both 0",
        "topic servicestatuschanged both 0",
        "topic modechanging both 0",
        "topic modechanged both 0",
        "topic boost both 0",
    ]

    if remote_user:
        lines.append(f"remote_username {remote_user}")
        if remote_password:
            lines.append(f"remote_password {remote_password}")

    if remote_use_tls:
        lines += [
            "bridge_tls_use_os_certs true",
            "bridge_tls_version tlsv1.2",
        ]

    os.makedirs(os.path.dirname(MOSQUITTO_CONF_PATH), exist_ok=True)
    with open(MOSQUITTO_CONF_PATH, "w") as f:
        f.write("\n".join(lines) + "\n")

# ---------------------------------------------------------------------------
# API / security
# ---------------------------------------------------------------------------

def configure_api(api_settings):
    section("API & Security")

    current_origin = api_settings.get('AllowedOrigins', f"http://{_get_ip()},https://{_get_ip()}")
    current_host = current_origin.split(",")[0].replace("http://", "").replace("https://", "").strip()
    host = ask("Hostname or IP of this device (used for CORS)", default=current_host or _get_ip())
    api_settings['AllowedOrigins'] = f"http://{host},https://{host}"

    current_secret = api_settings.get('Auth', {}).get('JwtSecret', '')
    print(f"\n  A random JWT secret will be generated automatically.")
    if ask_bool("  Generate now?", default=not bool(current_secret)):
        api_settings['Auth']['JwtSecret'] = generate_secret()
        ok("JWT secret generated")
    else:
        jwt_input = ask("JWT secret (min 32 chars)", default=masked_secret(current_secret), secret=True)
        api_settings['Auth']['JwtSecret'] = current_secret if jwt_input == "********" else jwt_input

    api_settings['Auth']['TokenExpiryHours'] = ask_int(
        "Token expiry (hours)", default=api_settings.get('Auth', {}).get('TokenExpiryHours', 12), min_val=1, max_val=720)

    api_settings['RetentionDays'] = ask_int(
        "Data retention (days)", default=api_settings.get('RetentionDays', 30), min_val=1, max_val=3650)

    current_kiosk_bypass = api_settings.get('Kiosk', {}).get('BypassIPs', [])
    kiosk_bypass_default = ", ".join(current_kiosk_bypass) if current_kiosk_bypass else ""
    api_settings.setdefault('Kiosk', {})
    api_settings['Kiosk']['BypassIPs'] = ask_ip_list(
        "Additional kiosk IP whitelist (comma-separated, optional)",
        default=kiosk_bypass_default
    )


def configure_display(shared_settings):
    section("Display & Naming")

    display = shared_settings.setdefault("Display", {})
    display['DashboardTitle'] = ask("Dashboard title", default=display.get('DashboardTitle', "Dashboard"))
    display['Sensor1Name'] = ask("Sensor 1 display name", default=display.get('Sensor1Name', "Rack"))
    display['Sensor2Name'] = ask("Sensor 2 display name", default=display.get('Sensor2Name', "Ambient"))
    display['Fan1Name'] = ask("Fan 1 display name", default=display.get('Fan1Name', "Intake Fan"))
    display['Fan2Name'] = ask("Fan 2 display name", default=display.get('Fan2Name', "Exhaust Fan"))
    display['Locale'] = ask("Display locale", default=display.get('Locale', "en-US"))
    display['TemperatureUnit'] = ask_choice("Temperature unit (C/F)", ["C", "F"], default=display.get('TemperatureUnit', "C").upper(), case_sensitive=False)
    display['DisableFanAnimations'] = ask_bool("Disable fan animations?", default=display.get('DisableFanAnimations', False))
    display['AirflowUnit'] = ask_choice("Airflow unit (m3h/CFM)", ["m3h", "CFM"], default=display.get('AirflowUnit', "m3h"), case_sensitive=False)
    display['Fan1MaxAirflow'] = ask_float("Fan 1 max airflow", default=display.get('Fan1MaxAirflow', 95), min_val=1, max_val=10000)
    display['Fan2MaxAirflow'] = ask_float("Fan 2 max airflow", default=display.get('Fan2MaxAirflow', 95), min_val=1, max_val=10000)

def configure_alerts(shared_settings):
    section("Alerts")

    defaults = shared_settings.setdefault("GlobalSettingsDefaults", {})
    defaults["DisableFanAlerts"] = ask_bool(
        "Disable fan disconnect alerts?",
        default=defaults.get("DisableFanAlerts", False),
    )

def configure_kiosk_setup(shared_settings):
    section("Kiosk Mode")

    kiosk_setup = shared_settings.setdefault("KioskSetup", {})
    enabled = ask_bool("Enable kiosk mode?", default=kiosk_setup.get("Enabled", False))
    kiosk_setup["Enabled"] = enabled

    if not enabled:
        return

    default_user = kiosk_setup.get("User") or os.environ.get("SUDO_USER") or os.environ.get("USER") or "pi"
    kiosk_setup["User"] = ask("Which local user should run kiosk mode", default=default_user)
    kiosk_setup["Inline"] = ask_bool("Enable inline layout?", default=kiosk_setup.get("Inline", False))
    kiosk_setup["HideCursor"] = ask_bool("Hide the mouse cursor automatically?", default=kiosk_setup.get("HideCursor", True))
    kiosk_setup["DesktopAutologin"] = ask_bool("Enable desktop autologin?", default=kiosk_setup.get("DesktopAutologin", True))
    kiosk_setup["DisableScreenBlanking"] = ask_bool("Disable screen blanking?", default=kiosk_setup.get("DisableScreenBlanking", True))
    kiosk_setup["Autostart"] = ask_bool("Start kiosk automatically on login?", default=kiosk_setup.get("Autostart", True))

def _get_ip():
    try:
        with socket.socket(socket.AF_INET, socket.SOCK_DGRAM) as sock:
            sock.connect(("8.8.8.8", 80))
            return sock.getsockname()[0]
    except Exception:
        try:
            host_ips = socket.gethostbyname_ex(socket.gethostname())[2]
            for ip in host_ips:
                if ip and not ip.startswith("127."):
                    return ip
        except Exception:
            pass
        return "raspberrypi.local"


def get_install_root(sensor_dir, api_dir):
    return os.path.commonpath([os.path.abspath(sensor_dir), os.path.abspath(api_dir)])


def get_shared_config_path(sensor_dir, api_dir):
    install_root = get_install_root(sensor_dir, api_dir)
    return os.path.join(install_root, "config", "settings.json")


def get_global_settings_db_path(shared_settings, install_root):
    connection_strings = shared_settings.get("ConnectionStrings", {})
    db_connection = connection_strings.get("WebApiDatabase", "")
    default_path = os.path.join(install_root, "api", "db", "LocalDatabase.db")
    return connection_string_to_db_path(db_connection, default_path)
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

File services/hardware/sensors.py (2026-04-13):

import time
import board
import busio
import adafruit_sht31d
import adafruit_mcp3xxx.mcp3004 as MCP
import digitalio
from adafruit_mcp3xxx.analog_in import AnalogIn
from w1thermsensor import W1ThermSensor, Sensor
from utils import debug_print, Verbose


class SensorController:
    def __init__(self, settings):
        self._sensor1_uid = self._normalize_uid(settings['sensor1Uid'])
        self._sensor2_uid = self._normalize_uid(settings['sensor2Uid'])
        self._sensor1_name = settings.get('sensor1Name', 'Sensor 1')
        self._sensor2_name = settings.get('sensor2Name', 'Sensor 2')
        self._sensor1 = None
        self._sensor2 = None
        self._sys_sensor = None
        self._mcp3004 = None

    @staticmethod
    def _normalize_uid(uid):
        return uid[3:] if isinstance(uid, str) and uid.startswith('28-') else uid

    def init(self):
        debug_print("Initializing I2C/SPI sensors...", Verbose.INFO)
        i2c = busio.I2C(board.SCL, board.SDA)
        spi = busio.SPI(clock=board.SCK, MISO=board.MISO, MOSI=board.MOSI)

        self._sys_sensor = adafruit_sht31d.SHT31D(i2c)
        self._sys_sensor.heater = False

        cs = digitalio.DigitalInOut(board.D5)
        self._mcp3004 = MCP.MCP3004(spi, cs)
        debug_print("System sensors initialized.", Verbose.INFO)

        self.init_sensor1()
        self.init_sensor2()

    def init_sensor1(self):
        debug_print(f"Initializing {self._sensor1_name} sensor...", Verbose.INFO)
        try:
            self._sensor1 = W1ThermSensor(Sensor.DS18B20, self._sensor1_uid)
            debug_print(f"{self._sensor1_name} sensor OK ({self._sensor1_uid})", Verbose.INFO)
        except Exception as ex:
            self._sensor1 = None
            debug_print(f"{self._sensor1_name} sensor ({self._sensor1_uid}) not connected: {ex}", Verbose.WARNING)

    def init_sensor2(self):
        debug_print(f"Initializing {self._sensor2_name} sensor...", Verbose.INFO)
        try:
            self._sensor2 = W1ThermSensor(Sensor.DS18B20, self._sensor2_uid)
            debug_print(f"{self._sensor2_name} sensor OK ({self._sensor2_uid})", Verbose.INFO)
        except Exception as ex:
            self._sensor2 = None
            debug_print(f"{self._sensor2_name} sensor ({self._sensor2_uid}) not connected: {ex}", Verbose.WARNING)

    def get_sensor1_temp(self):
        if self._sensor1 is None:
            debug_print(f"{self._sensor1_name} sensor not connected", Verbose.WARNING)
            return 0
        try:
            temp = self._sensor1.get_temperature()
            debug_print(f"{self._sensor1_name} temperature: {temp}c", Verbose.DEBUG)
            return temp
        except Exception as ex:
            debug_print(f"Error getting {self._sensor1_name} temperature: {ex}", Verbose.WARNING)
            return 0

    def get_sensor2_temp(self):
        if self._sensor2 is None:
            debug_print(f"{self._sensor2_name} sensor not connected", Verbose.WARNING)
            return 0
        try:
            temp = self._sensor2.get_temperature()
            debug_print(f"{self._sensor2_name} temperature: {temp}c", Verbose.DEBUG)
            return temp
        except Exception as ex:
            debug_print(f"Error getting {self._sensor2_name} temperature: {ex}", Verbose.WARNING)
            return 0

    def get_system_sensor(self):
        humidity = 0
        temperature = 0
        try:
            humidity = self._sys_sensor.relative_humidity
            debug_print(f"System humidity: {humidity}", Verbose.DEBUG)
        except Exception as ex:
            debug_print(f"Unable to get system humidity: {ex}", Verbose.WARNING)
        try:
            temperature = self._sys_sensor.temperature
            debug_print(f"System temperature: {temperature}", Verbose.DEBUG)
        except Exception as ex:
            debug_print(f"Unable to get system temperature: {ex}", Verbose.WARNING)
        return {'temp': temperature, 'humidity': humidity}

    def get_system_current(self):
        chan = AnalogIn(self._mcp3004, MCP.P0)
        num_iterations = 50
        vref = 1.6310
        span = 0.0000495
        sum_voltage = 0.0
        for _ in range(num_iterations):
            sum_voltage += chan.voltage
            time.sleep(0.10)
        avg_voltage = sum_voltage / num_iterations
        current = (avg_voltage - vref) / span
        debug_print(f"ASC712 Voltage: {avg_voltage:.10f}", Verbose.DEBUG)
        debug_print(f"ASC712 Current(mA): {current:.10f}", Verbose.DEBUG)
        return current

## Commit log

2026-04-23 Add multi-mode fan condition control
2026-05-20 Add fan alert toggle and installation changelog

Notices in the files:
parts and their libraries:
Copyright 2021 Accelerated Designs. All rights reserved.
